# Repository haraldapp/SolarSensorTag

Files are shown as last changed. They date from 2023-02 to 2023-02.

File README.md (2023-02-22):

# SolarSensorTag
Smarthome Sensor mit Akku und Solarzelle  
Status: erste Prototypen als Temperatur+Luftfeuchte Sensor laufen seit 08/2022

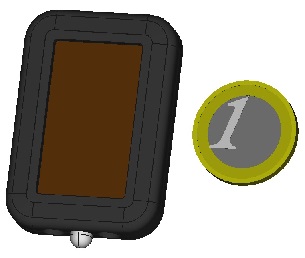
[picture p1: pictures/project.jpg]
> 

##  Features
- kleine Abmessungen
- Akku Ladungserhaltung bei etwas Tageslicht ohne direkte Sonne
- vielfache Bestückungsmöglichkeiten mit unterschiedlichen Sensoren
- Solarzelle und Gehäuse können von einer sehr preiswerten Mini-Taschenlampe verwendet werden (auch China Clones) - *"Solar Power Flash Light"* googeln

## Hardware
- Prozessor der SiLabs EFM32 Serie
- CC1101 Modul
- opt. EEPROM
- Solarzelle 4V
- Akku Kopfzelle, z.B. VL2020
- Dual-Color LED
- zum Gehäuse passende Leiterplatte
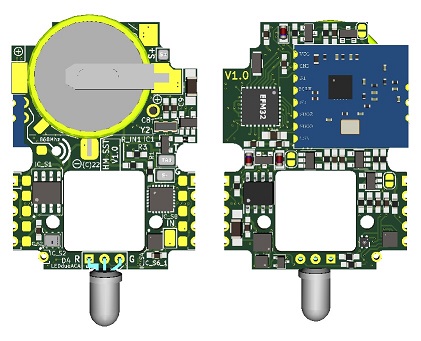
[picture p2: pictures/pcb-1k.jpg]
  
- Aufbau
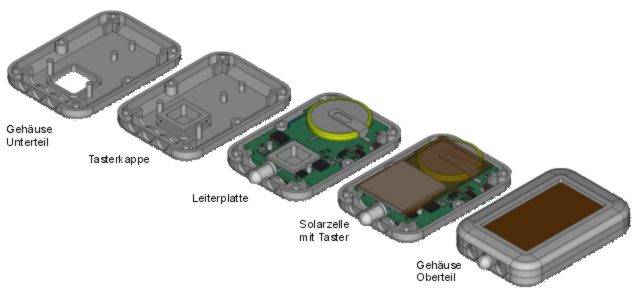
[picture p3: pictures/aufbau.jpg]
   
 
## Software
- Entwicklungsumgebung Silicon Labs Simplicity Studio mit GeckoSDK
- Unfangreiches eigenes API mit Arduino ähnlichen Funktionen, das auf dem SiLabs GeckoSDK aufsetzt  
  (damit sind Sourcecode Teile aus Arduino Sketches einsetzbar)
- Watchdog
- Schutz des Akkus vor Überladung durch Software
- Menü zur Bedienung mit einem Button 
- Debug Ausgabe (emuliert)
- verschiedene RF Protokolle sind in der Entwicklung, u.a.  
  Homematic [ASKSINPP](https://github.com/pa-pa/AskSinPP)
- STM32 Version geplant, wenn MCU's verfügbar sind 
  
## Projekte
- [HM-WDS10-TH-I](projects/HM-WDS10-TH/README.md "")/HM-WDS10-TH-O Temperatur/Feutigkeitssensor

## Add on's
- Halter für Blumentöpfe [```JPG```](addon/plantsticker/plant-sticker.jpg) [```STL```](addon/plantsticker/plant-sticker.stl)
   
## Getting Started
- keine Zeit? dann direkt zu einer Projektseite wechseln
- Schaltplan mit allen Optionen [```PDF```](efm32/schematics/SolarSensorTagEFM32-schematics.pdf) [```JPG```](efm32/schematics/SolarSensorTagEFM32-schematics.jpg)
- Bauteileliste mit allen Optionen [```PDF```](efm32/partlist/SolarSensorTagEFM32-parts.pdf)
- PCB im Verzeichnis efm32/pcb/gerber
- Bestückungsplan [```PDF```](efm32/pcb/assembly/SolarSensorTagEFM32-assembly.pdf)

## Entwicklung
- Programmieradapter [```README```](develop/progadapt/README.md)

## Lizenz
- [Creative Commons 3.0](http://creativecommons.org/licenses/by-nc-sa/3.0/de/)  
  
<br><br>
   
**Thanks to**
+ [pa-pa](https://github.com/pa-pa) für seine Arbeit an ASKSINPP

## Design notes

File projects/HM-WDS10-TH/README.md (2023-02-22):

# HM-WDS-10
Temperatur+Luftfeuchte Sensor for Homematic

## Bauteile
- die STT Leiterplatte wird mit wenigen Bauteilen bestückt  
  Bestückungsliste [``PDF``](SolarSensorTag-THSensor-Parts.pdf)
- zum Einsatz kommt ein VL2020/HFN Akku mit Lötfahnen der direkt auf der Leiterplatte bestückt wird  

## Aufbau

Als Basis für Solarzelle und Gehäuse dient eine Mini-Taschenlampe (hier China Clone). 

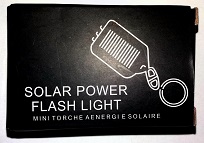
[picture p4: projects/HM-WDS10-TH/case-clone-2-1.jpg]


Bei manchen Geäusen muß man noch einen/zwei Abstandhalter oder Stifte (rot) entfernen damit die Leiterplatte rein passt. Einige Clones haben statt einem Akku nur eine CR2032 Batterie - aber bisher alle - eine funktionierende Solarzelle. Die Leiterplatte mit Taster ist dann manchmal so aufgeklebt, daß man die Anschlüsse der Solarzelle nicht sieht.

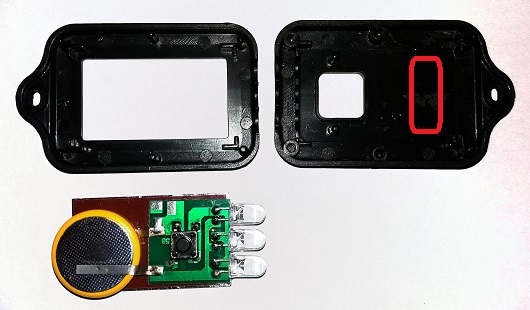
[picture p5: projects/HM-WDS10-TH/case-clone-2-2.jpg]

 
Ggf. Leiterplatte mit Taster ablösen und an der richtigen Stelle aufkleben. Batterie und LEDs entfernen und Anschlussdrähte anlöten.  
Achtung (!) sollte die Solarzelle bisher nicht angeschlossen sein:  
Die Kontakte der Solarzelle lassen sich meist nur mit Niedertemperatur Lötzinn verlöten, da diese sonst wegbrennen. Hier ist es besser das (+) Kabel mit einem Tropfen UV Kleber zu befestigen und die Verbindung mit Silberleitlack herzustellen.

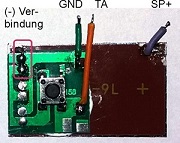
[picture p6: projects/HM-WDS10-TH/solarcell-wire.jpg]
 

Oberseite der VL2020 Batterie mit einem Stück Tesa isolieren. 
Verbindungen an die Leiterplatte anlöten und alles ins Gehäuse einpassen.

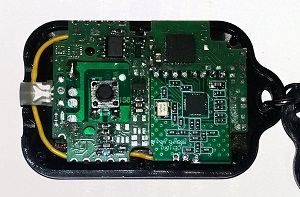
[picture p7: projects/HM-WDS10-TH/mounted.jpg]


## Bedienung
- Die Bedieung erfolt über den Taster. Anders als bei bei Standard Homematic Sensoren ist ein Menü implementiert über das mehrere Funktionen auswählbar sind.  
   [siehe doc](/source/doc/menu-states.jpg)

## Lizenz
- [Creative Commons 3.0](http://creativecommons.org/licenses/by-nc-sa/3.0/de/)  
  
<br><br>
**Thanks to**
+ [pa-pa](https://github.com/pa-pa) für seine Arbeit an ASKSINPP

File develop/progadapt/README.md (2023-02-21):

# SST Programming Adapter

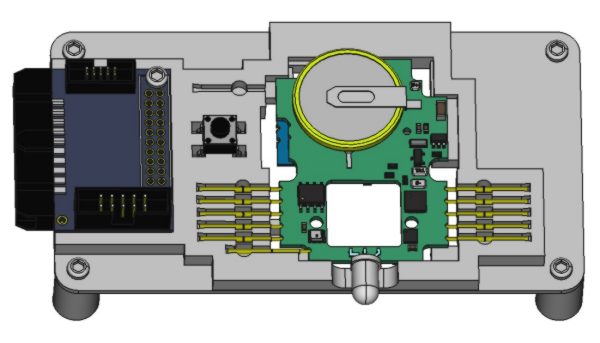
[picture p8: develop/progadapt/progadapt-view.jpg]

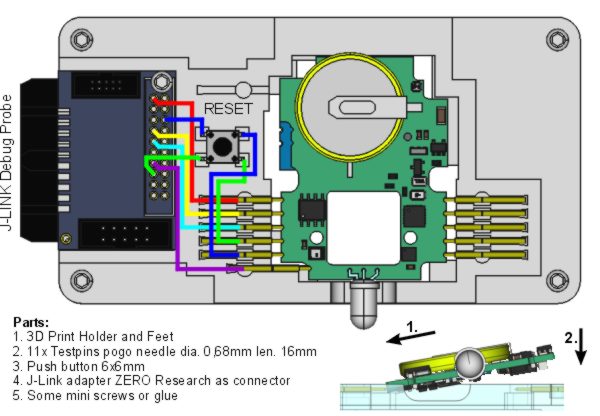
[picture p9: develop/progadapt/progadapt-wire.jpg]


#  3D Print
- 1x body [```STL```](progadap-body.stl)
- 4x feet [```STL```](progadap-body.stl)

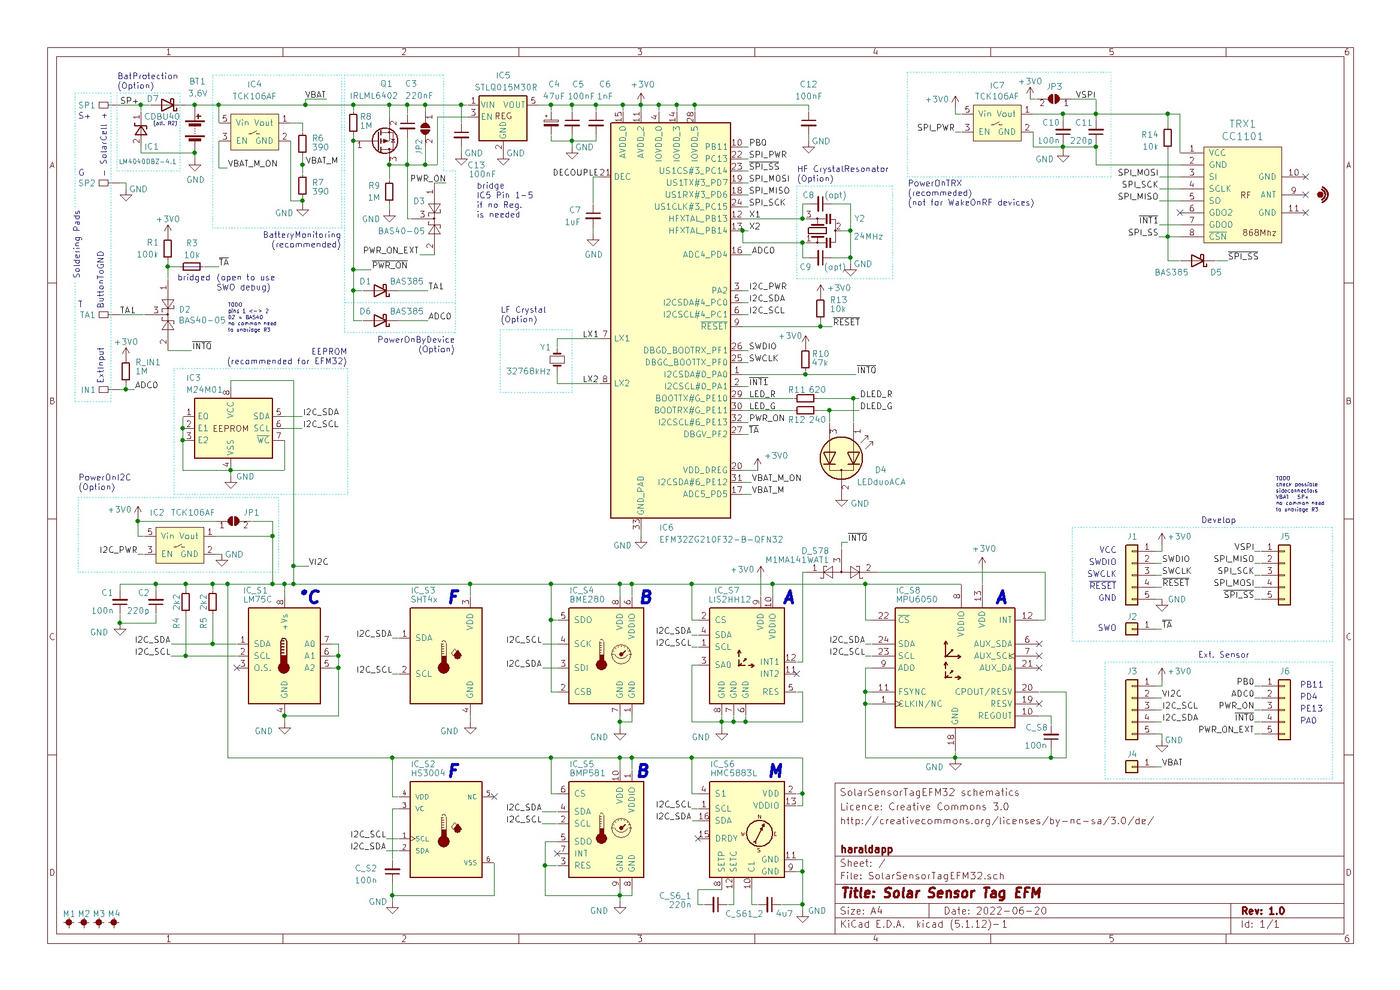
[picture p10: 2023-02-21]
efm32/schematics/SolarSensorTagEFM32-schematics.jpg

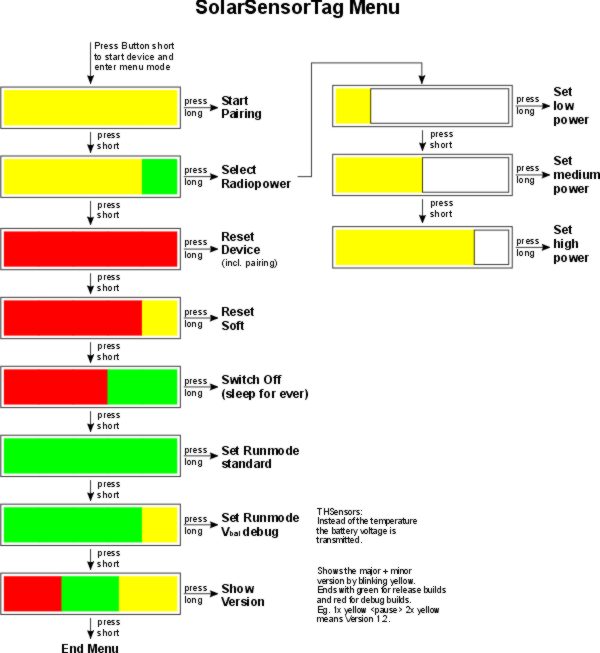
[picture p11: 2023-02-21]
source/doc/menu-states.jpg

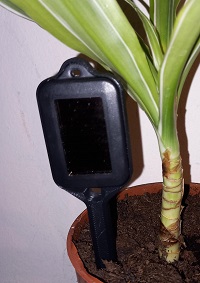
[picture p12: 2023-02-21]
addon/plantsticker/plant-sticker.jpg

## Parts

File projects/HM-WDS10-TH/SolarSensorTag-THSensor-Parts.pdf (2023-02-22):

## Solar Sensor Tag EFM THSensor parts

Reduced part list for TH sensors with VL2020 battery

Ref | Value | Size / Case / Spec | PartNo. / Alternatives
THSensor project
IC3 | M24256 | SOIC-8 3,9mm P1.27mm, EEPROM | M24256E-FMN6TP M24256-BRMN6TP M24M01-DFMN6TP
IC5 | Reg. 3,0V | bridge pin 1-5
IC6 | EFM32 | QFN-32, MCU AMTEL (EFM32HG210F32 for release not tested) | EFM32HG210F64-B-QFN32
IC7 | TCK106AF | SOT23-5 | TCK106AF,LF
IC_S3 | SHT4x | SHT4x 1.5x1.5mm P0.8mm | SHT40-AD1B-R2 SHT40A SHT41A
D2 | BAS40-05 | SOT-23, common cathode, low leakage or bridge pin 2-3 | BAS40-05 BAS70-05 BAT54C
D4 | LED RedGreen | 5mm/3mm, THT, 3Pin, common cathode | WP59SURKCGKW
D5 | BAS385 | MicroMELF, 0603, 0805, low leakage | CDBU40
D7 | 150 | 0603 (resistor instead of diode)
C1 | 100n | 0603 | CL10B104KA8NNWC
C4 | 47uF 6,3V | 1206, X5R, poss. Tantal 1210 low height | CL31A476MQHNNNE
C5 | 100nF | 0603
C6 | 1nF | 0603
C7 | 1uF | 0805 | CL21B105KAFNNNE
C10 | 100nF | 0603
C11 | 220pF | 0603
C12 | 100nF | 0603
R3 | 10k | unbridge for debug
R4 | 6k8 | 0603, I2C pullup
R5 | 6k8 | 0603, I2C pullup
R10 | 47k | 0603
R11 | 620 | 0603
R12 | 240 | 0603
R13 | 10k | 0603
R14 | 10k | 0603
JP1 | | bridge
TRX1 | CC1101 868MHz | 19x17mm module
ANT | 83mm 868MHz | isolated wire antenna
BT1 | VL2020 | Li.Va. battery cell with solder tabs Charge end 3.4V, Discharge end: 2,5V! max. short load current not spec.! | VL2020/1HF VL2020/HFN BL2020
TA1 | PushButton | 6x6mm … from CASE
SP1 | SC-3722-9 | SolarPanel 4V, 37x22mm … from CASE
LP | HM SST V1.0 | PCB, 31,2x41,2mm, 4-layer
CASE | | SolarPowerFlashLight

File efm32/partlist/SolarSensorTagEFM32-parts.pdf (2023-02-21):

## Solar Sensor Tag EFM parts

Ref | Value | Size / Case / Spec | PartNo. / Alternatives
Core
IC5 | Reg. 3,0V | SOT23-5, nano power LDO regulator | STLQ015M30R SPX3819M5-L-3-0/TR
IC6 | EFM32 | QFN-32, MCU AMTEL | EFM32HG210F64-B-QFN32
D2 | BAS40-05 | SOT-23, common cathode, low leakage | BAS40-05 BAS70-05 BAT54C
D4 | LED RedGreen | 5mm/3mm, THT, 3Pin, common cathode | WP59SURKCGKW
D5 | BAS385 | MicroMELF, 0603, 0805, low leakage | CDBU40
D7 | CDBU40 | 0603
C1 | 100n | 0603 | CL10B104KA8NNWC
C2 | 220p | 0603
C4 | 47uF 6,3V | 1206, X5R, poss. tantal 1210 low height | CL31A476MQHNNNE
C5 | 100nF | 0603
C6 | 1nF | 0603
C7 | 1uF | 0805 | CL21B105KAFNNNE
C12 | 100nF | 0603
R1 | 100k | 0603 | (optional)
R3 | 10k | 0603, bridged by default
R4 | 2k2 / 4k7 | 0603, I2C pullup
R5 | 2k2 / 4k7 | 0603, I2C pullup
R10 | 47k | 0603
R11 | 620 | 0603
R12 | 240 | 0603
R13 | 10k | 0603
R14 | 10k | 0603
TRX1 | CC1101 868MHz | 19x17mm module
ANT | 83mm 868MHz | isolated wire antenna
BT1 | LIR2025 | Li.Ion/Li.Po/Li.Va battery cell with solder tabs (2025 + 2032 only with high case 0) | LIR2025 BMW LIR2025-LBY2 (1,60 R) (VL2020 see options) (ML2020 see options)
TA1 | PushButton | 6x6mm … see CASE
SP1 | SC-3722-9 | SolarPanel 4V, 37x22mm … see CASE
LP | HM SST V.10 | PCB, 31,2x41,2mm, 4-layer
CASE | | 3D-Print or SolarPowerFlashLight
HF Crystal Resonator (option)
Y2 | 24MHz | SMD3215 Resonator 3pin 3.2x1.3mm | CSTNE24M0VH3C000R0 CSTNE24M0VH5T000R0
C8 | (opt) | 0603, optional
C9 | (opt) | 0603, optional
LF Crystal (option)
Y1 | 32768kHz | SMD3215 2pin 3.2x1.5mm | SC32S-7PF20PPM (0,43 D) (0,34 M)

EEPROM (option, recommended)
IC3 | M24256 | SOIC-8 3,9mm P1.27mm, EEPROM >=256kBit (32kB) | M24256E-FMN6TP M24256-BRMN6TP

M24M01-DFMN6TP
BatteryMonitoring (option, recommended for LiIo battery and 3V reg.)
IC4 | TCK106AF | SOT23-5
R6 | 390 / 100 | 0603
R7 | 390 / 220 | 0603
PowerOnTRX (option, recommended)
IC7 | TCK106AF | SOT23-5 | TCK106AF,LF
C10 | 100n | 0603
C11 | 220p | 0603
PowerOnI2C (option)
IC2 | TCK106AF | SOT23-5
PowerOnByDevice (option)
Q1 | IRLML6402 | SOT-23 | IRLML2244 IRLML9301
D1 | BAS385 | MicroMELF, 0603, 0805, low leakage
D3 | BAS40-05 | SOT-23, common cathode, low leakage | BAS70-05 BAT54C
C3 | 220nF | 0603
R8 | 1M | 0603
R9 | 1M | 0603
BatProtection (option, may only be needed for outdoor/direct sunlight)
IC1 | LM4040DBZ-4.1 | SOT-23 | LM4040DIM3-4.1 LM4040DYM3-4.1

BatteryVanadium (option) (3,0V vanadium rechargeable battery)
BT1 | VL2020 | Li.Va. battery cell with solder tabs Charge end 3.4V, Discharge end: 2,5V! max. short load current not spec.! | VL2020/1HF (2,70) VL2020/HFN BL2020
D7 | 150 | 0603, resistor
R4 | 6k8 | 0603, I2C pullup
R5 | 6k8 | 0603, I2C pullup
IC1 | LM4040DBZ-3.3 | SOT-23
IC5 | Reg. 3,0V | bridge pin 1-5
Q1 | IRLML6402
D1 | BAS385
D3 | BAS40-05
D6 | BAS385
C3 | 220nF
R8 | 1M
R9 | 1M
Sensor 0: (no sensor, e.g. 1 channel remote control) NanoPower see PowerOnByDevice
D6 | BAS385 | MicroMELF, 0603, 0805, low leakage
TA2 | PushButton | 6x6mm, ext. KonfigBtn IN1 GND
Sensor 1: Temperature
IC_S1 | LM75C | SOIC-8 P1.27mm
Sensor 2: Temperature + Humidity
IC_S2 | HS3004 | 6LGA P1.0mm | HS3004 (2,19 M) (2,14 D)
C_S2 | 100n | 0603
Sensor 3: Temperature + Humidity
IC_S3 | SHT4x | SHT4x 1.5x1.5mm P0.8mm | SHT40-AD1B-R2 SHT40A

SHT41A
Sensor 4: Temperatur + Barometer
IC_S4 | BME280 | Bosch_LGA | BMP280 (6,88 D)
Sensor 5: Temperatur + Barometer
IC_S5 | BMP581 | Bosch_HLGA | BMP581 (5,60 D)
Sensor 6: Compass (experimental, design rule „no copper under the case“ cannot be implemented)
IC_S6 | HMC5883L | LGA-16 P0.5mm
C_S61_1 | 220n | 0603
C_S61_2 | 4u7 | 1206
Sensor 7: Accelerometer (3-Axxis)
IC_S7 | LIS2HH12 | LGA-12 P0.5mm | LIS2HH12 (1,65 D)
D_S78 | M1MA141WAT 1 | SOT-323, SC-70, common anode, low leakage | M1MA141WAT1 DAP202U

Sensor 8: Accelerometer (6-Axxis)
IC_S8 | MPU6050 | QFN-24 P0.5mm | MPU-6050 (7,60 M) ICM-20689 TDK (6,66 D)
D_S78 | M1MA141WAT 1 | SOT-323, SC-70, common anode | M1MA141WAT1 DAP202U
C_S8 | 100n | 0603
Sensor 9: Ext. Input/PushButton/Switch/WindowContact
R_IN1 | 1M | 0603 | or as C 47nF
Sensor 10: 1/2-channel remote control
R_IN1 | 47k | 0603
SW_EXT | SW1 | 6x6mm external config. switch
Sensor EXT: staggered sensor PCB with solder connections J3 J4 J6
R1 | 100k | not mounted
R3 | 10k | not mounted
R_IN1 | 1M | not mounted
IC_S1 | LM75C | not mounted
IC_S2 | HS3004 | not mounted
C_S2 | 100n | not mounted
IC_S6 | HMC5883L | not mounted
C_S61_1 | 220n | not mounted
C_S61_2 | 4u7 | not mounted
IC_S4 | BME280 | not mounted
IC_S8 | MPU6050 | not mounted
D_S78 | BAS70-06 | not mounted
C_S8 | 100n | not mounted

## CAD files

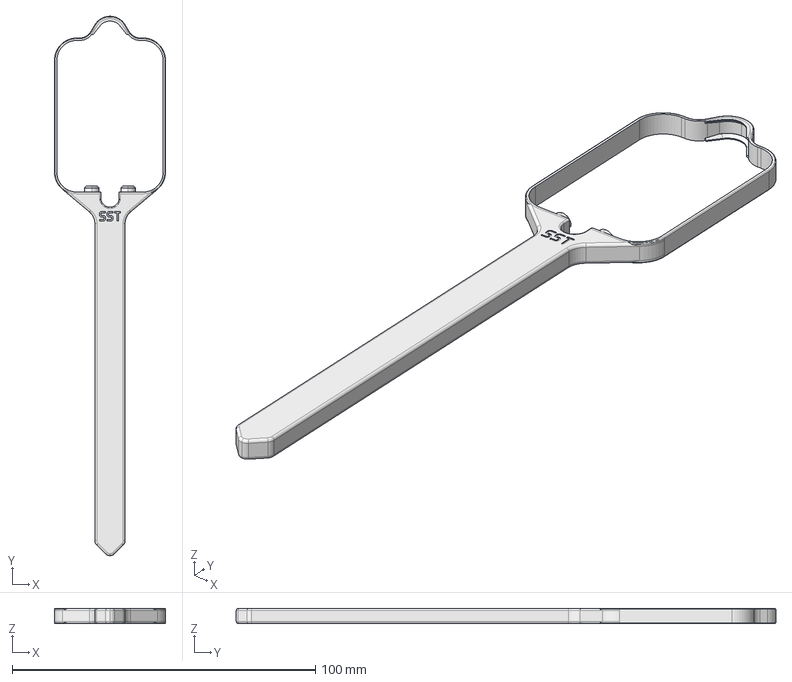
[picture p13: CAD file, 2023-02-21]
addon/plantsticker/PlantSticker.FCStd
36.6 x 178.0 x 5.00 mm

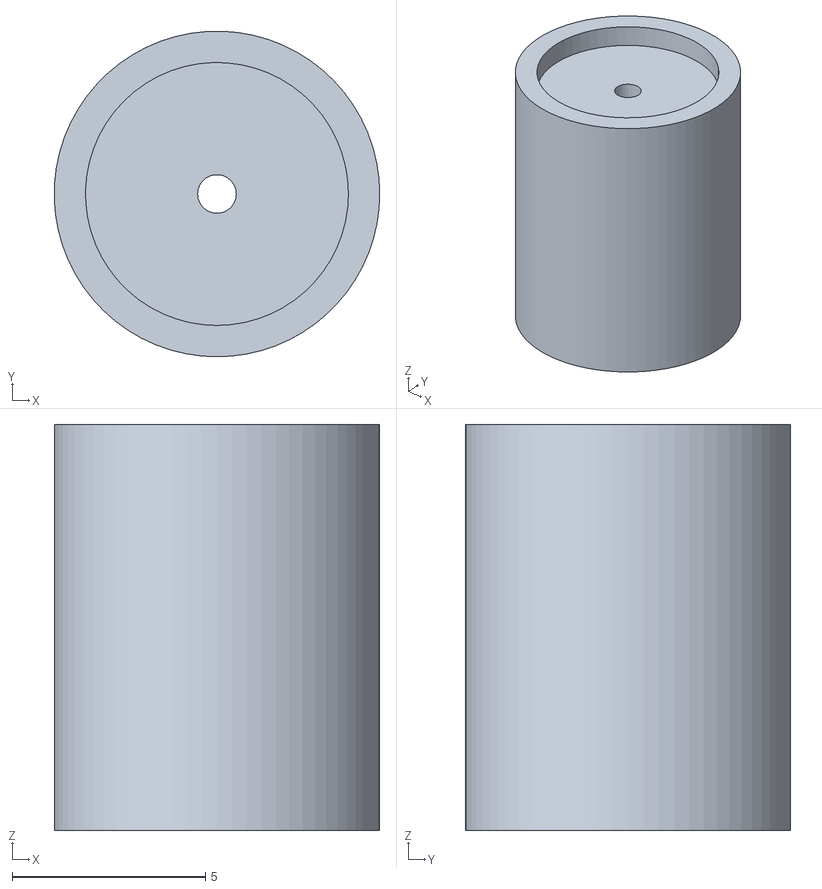
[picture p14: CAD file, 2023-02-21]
develop/progadapt/progadapt-feet.stl
8.42 x 8.42 x 10.5

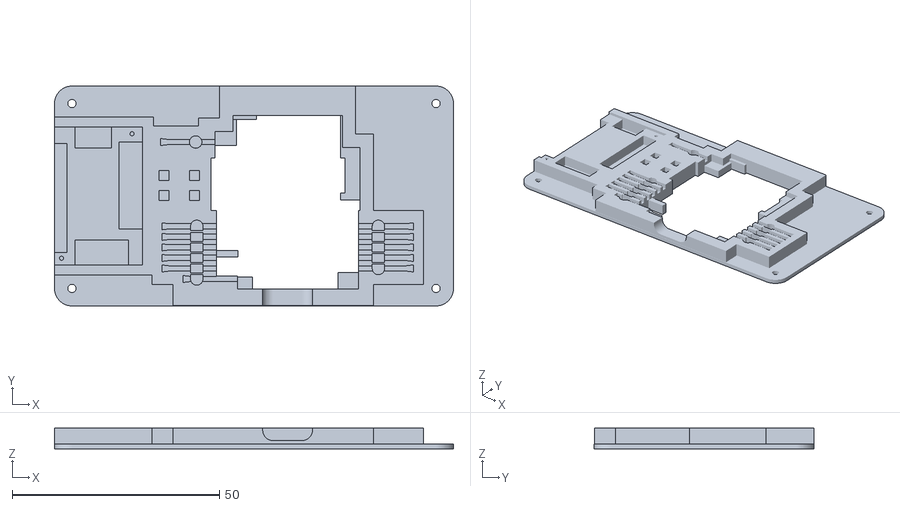
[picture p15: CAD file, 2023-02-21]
develop/progadapt/progadapt-body.stl
96.2 x 53.0 x 5.00

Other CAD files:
addon/plantsticker/plant-sticker.stl

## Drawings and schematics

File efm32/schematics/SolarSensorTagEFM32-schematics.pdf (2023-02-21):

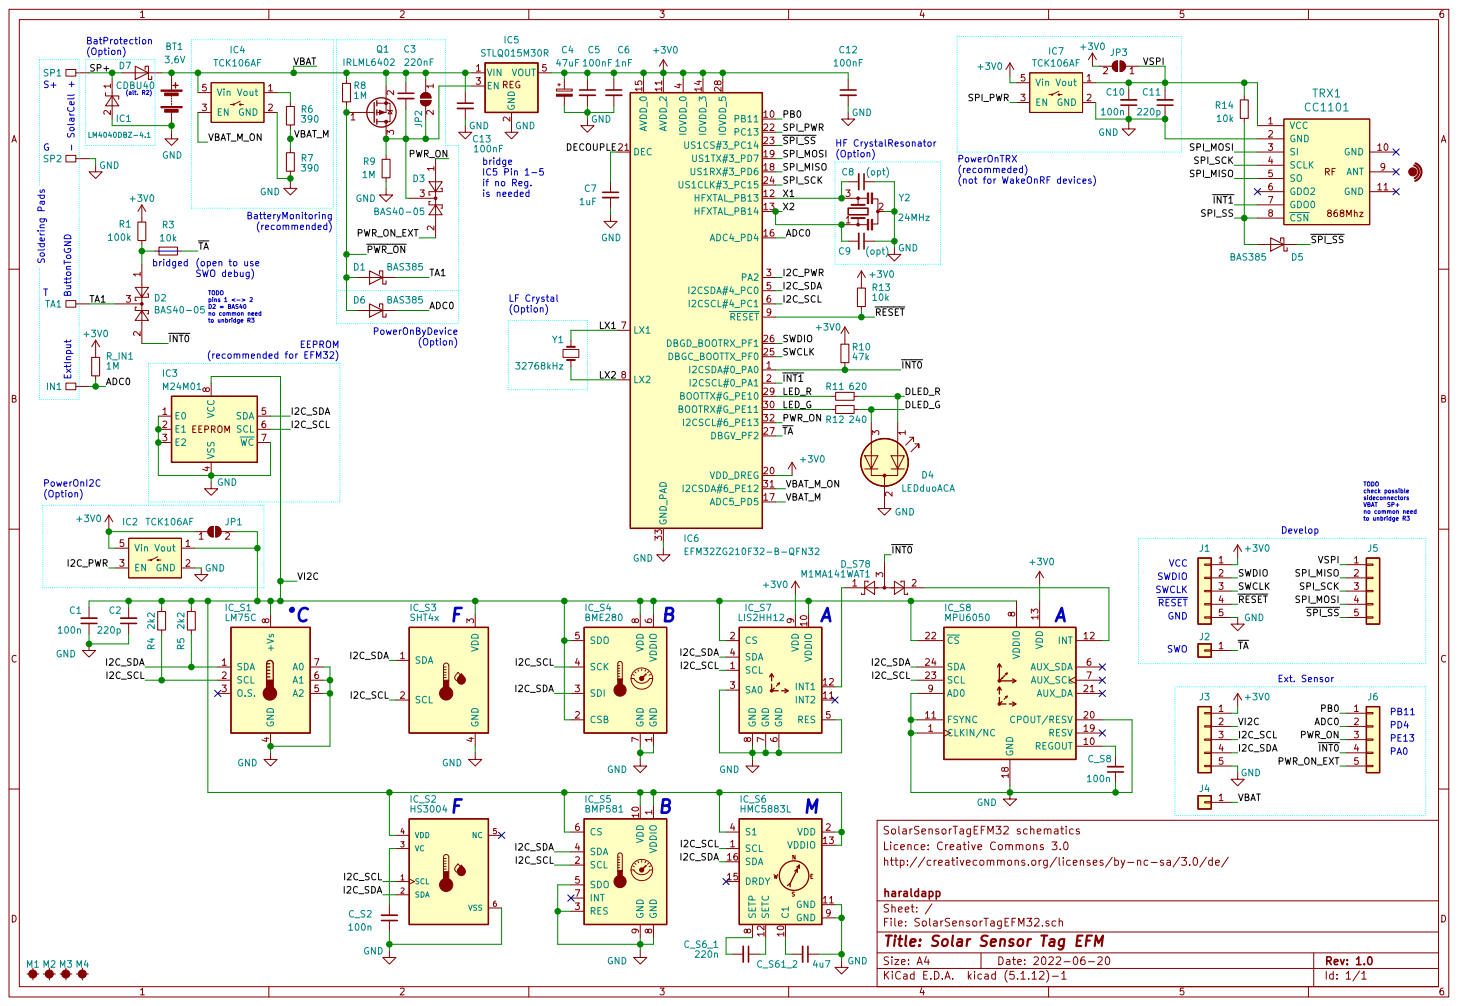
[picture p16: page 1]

to unbridge R3 TODO pins 1 <-> 2 D2 = BAS40

4 SDA 5 SCL 6 WC 7 VCC

http://creativecommons.org/licenses/by-nc-sa/3.0/de/ Licence: Creative Commons 3.0 SolarSensorTagEFM32 schematics C1

IC_S1 | IC_S4 BME280 | IC_S7 | IC_S8 MPU6050

1 CSB 2 SDI 3 SCK 4 SDO 5 VDDIO

1 VDD 10 SCL 2 RES 3 SDA 4 SDO 5 CS 6

File: SolarSensorTagEFM32.sch Sheet: / haraldapp

Id: 1/1 Title: Solar Sensor Tag EFM

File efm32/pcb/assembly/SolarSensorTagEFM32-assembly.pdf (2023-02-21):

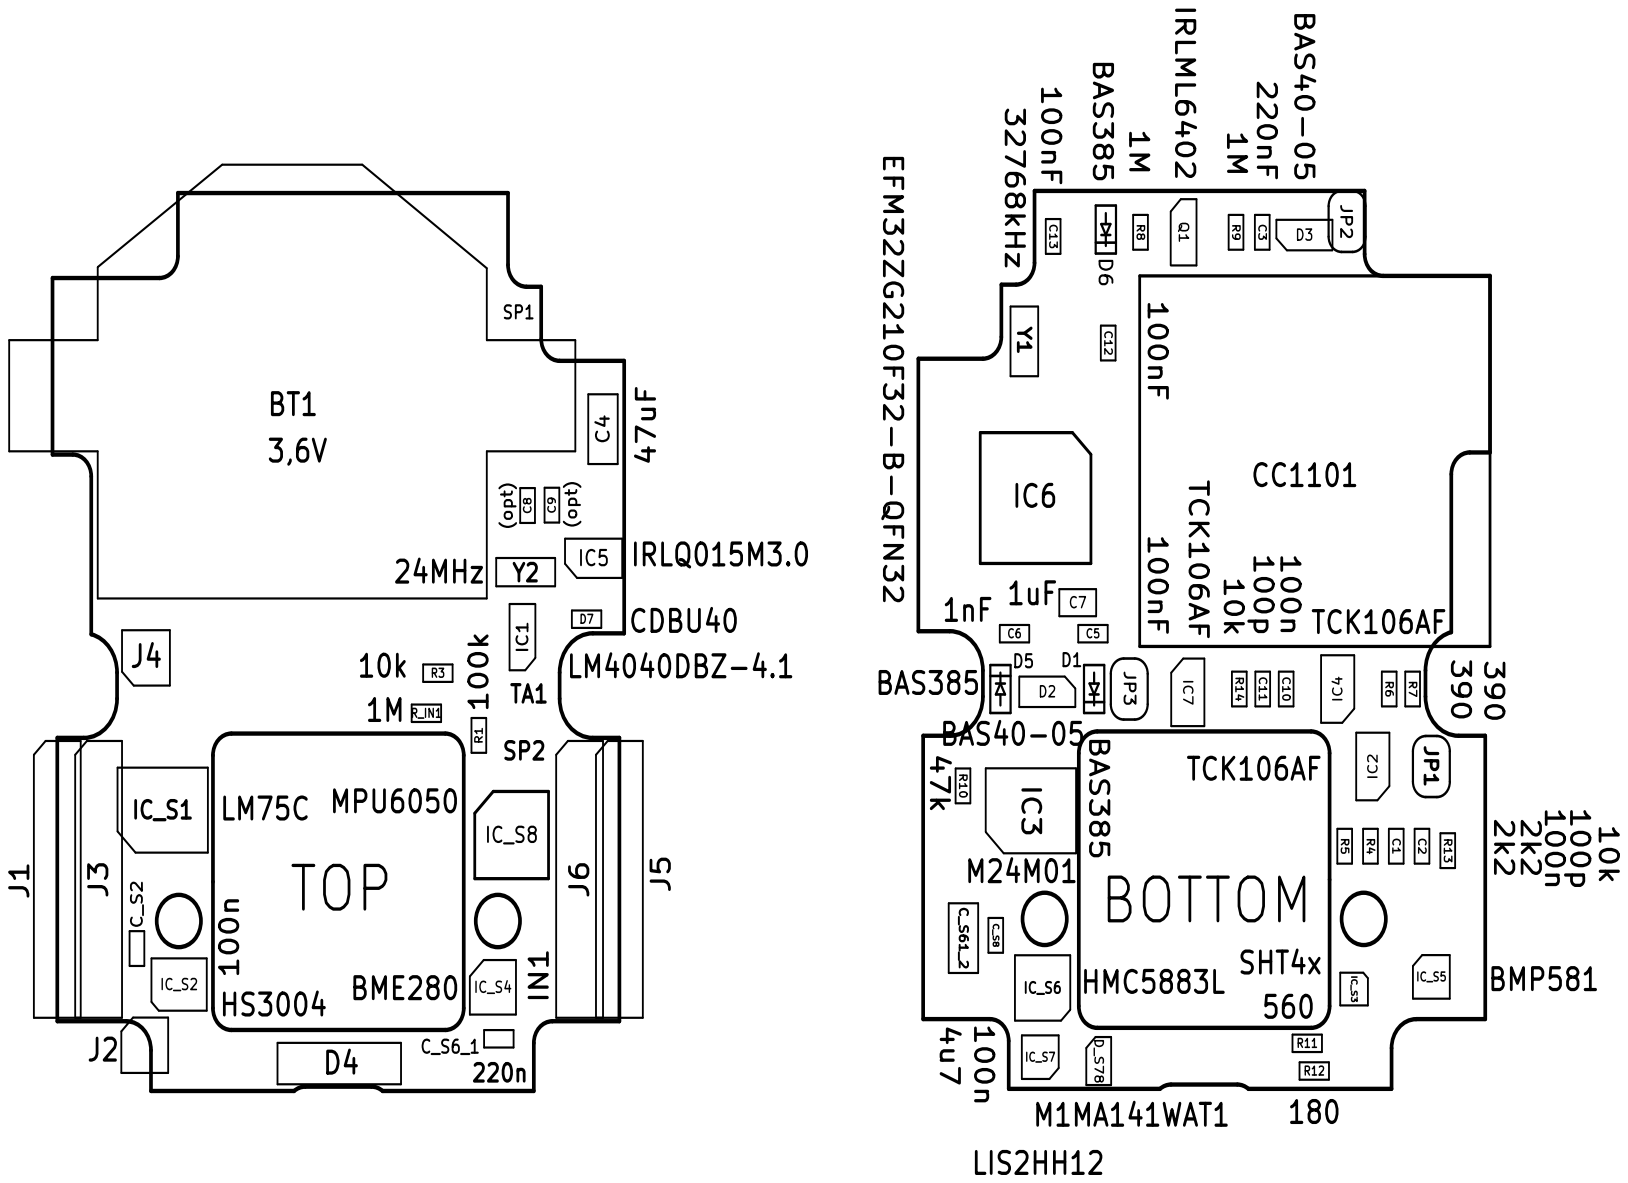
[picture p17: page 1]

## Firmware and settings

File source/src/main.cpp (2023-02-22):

//- -----------------------------------------------------------------------------------------------------------------------
// SolarSensorTag
// 2022-09-01 haraldapp Creative Commons - http://creativecommons.org/licenses/by-nc-sa/3.0/de/
//- -----------------------------------------------------------------------------------------------------------------------
// file: main.cpp
// Implements a ASKSINPP based code for some sensors on the SolarSensorTag hardware
//
// REFERENCES
// [1] AskSinPP https://github.com/pa-pa/AskSinPP and https://asksinpp.de/
//- -----------------------------------------------------------------------------------------------------------------------

// map aduino
#include "sst_arduino_geckosdk.h"

// to compile an individual SST sensor:
//  create a new configuration file, eg. sst_config_HM-WDS10-TH-O.h
//  set/add a build configuration with global define, eg. SST_CONFIG_FILE="sst_config_HM-WDS10-TH-O.h"
#ifdef SST_CONFIG_FILE
#include SST_CONFIG_FILE
#else
#error "no global define SST_CONFIG_FILE"
#endif

// Version
#define SST_VER_MAJOR 1
#define SST_VER_MINOR 2

// TODO implement asksin option wake up on radio
// TODO implement asksin AES using EFM32 hardware
// TODO implement SST option battery monitor
// TODO implement periodic polling for configuration changes (otherwise we have to push the button somewhere mounted devices)
// TODO optimize power consumption
// TODO    eg. asksin Radio-CC1101.h init() sets always MaxPower
// TODO    eg. asksin Radio-CC1101.h reduce EM0 runtime, check delays, current consumption is 47ms 5mA + 24ms 32mA
// TODO    eg. check if scaling down clocks has some effect on power consumption
// TODO optimize some code size

// asksin radio pins (radio.h)
#define MISO SPI_MISO_APIN
#define MOSI SPI_MOSI_APIN
#define SCK  SPI_SCK_APIN

// asksin storage (eeprom)
#ifndef SST_OPT_EEPROM_I2CADDR
#define SST_OPT_EEPROM_I2CADDR 0xA0
#endif
#if SST_OPT_EEPROM==0 // internal flash
 #error "eeprom internal flash not implemented"
#elif SST_OPT_EEPROM==1 // M24M01
 #define STORAGEDRIVER SST_EEPROM_M24MXX<SST_OPT_EEPROM_I2CADDR,128,256>
#elif  SST_OPT_EEPROM==2 // M24256
 #define STORAGEDRIVER SST_EEPROM_M24MXX<SST_OPT_EEPROM_I2CADDR,32,64>
#elif  SST_OPT_EEPROM==9 // M24xx compatible
 #ifndef SST_OPT_EEPROM_SIZE
 #error "SST_OPT_EEPROM_SIZE not defined"
 #endif
 #ifndef SST_OPT_EEPROM_PAGE
 #error "SST_OPT_EEPROM_PAGE not defined"
 #endif
 #define STORAGEDRIVER SST_EEPROM_M24MXX<SST_OPT_EEPROM_I2CADDR,SST_OPT_EEPROM_SIZE,64>
#endif

// asksin library
#define SPI_MODE0     0   // radio.h use template class LibSPI
#define EnableInterrupt_h   // asksinpp.h we have interrupts, do not use pin polling
#include "asksinpp.h"
#include "Register.h"
#include <MultiChannelDevice.h>
#include <Weather.h>
using namespace as;

// device info
static struct DeviceInfo devinfo = {
    {0x4e,0x52,0x12},            // Device ID
    "SST1234567",                // Device Serial
    {0x00,DEVICE_MODEL},         // Device Model
    0x10,                        // Firmware Version
    as::DeviceType::DEVICE_TYPE, // Device Type
    {0x01,0x00}                  // Info Bytes
};
// device ID and Serial from EFM32 chip ID (like USE_HW_SERIAL)
// remark:
//  to avoid modifying asksin code (see define USE_HW_SERIAL/Device.h)
//  we use a memory structure and initialize ID and Serial
//  early within a class constructor
SST_InitDeviceInfoFromHWSerial initDevInfo(devinfo.DeviceID,devinfo.Serial);

// radio
#ifndef RADIO_SENDDELAY
 #define RADIO_SENDDELAY 100
#endif
// custom config: reduce radio power
#define CONFIG_RADIOPOWER 3 // custom config offsets see asksinpp.h: CONFIG_FREQ1=0, CONFIG_FREQ2=1, CONFIG_BOOTSTATE=2
static uint8_t _sst_custom_radio_freq1=0;
static uint8_t _sst_custom_radio_freq2=0;
enum { sst_radiopower_notset=0, sst_radiopower_low=1, sst_radiopower_normal=2, sst_radiopower_max=3 };
static uint8_t _sst_custom_radio_power=sst_radiopower_normal;
typedef LibSPI<SPI_SS_APIN> SPIType;
#if !defined(SST_OPT_POWERON_TRX) || (SST_OPT_POWERON_TRX==0)
 typedef CC1101Radio<SPIType,INT1_APIN,NO_APIN,RADIO_SENDDELAY> RadioBaseType;
#else
 typedef CC1101Radio<SPIType,INT1_APIN,SPI_PWR_APIN,RADIO_SENDDELAY> RadioBaseType;
#endif
class RadioType : public RadioBaseType {
public:
  bool init () {
    // CC1101Radio:init() initializes
    //   CC1101_PATABLE=PA_MaxPower
    //   CC1101_FREQ2=0x21, CC1101_FREQ1=0x65, CC1101_FREQ0=0x6A (868.3 MHz)
    bool ret=RadioBaseType::init();
    if ( ret )  { // set custom config values on every radio init
      if( _sst_custom_radio_freq1>=0x60 && _sst_custom_radio_freq1<=0x6A )
        this->tuneFreq(0x21, _sst_custom_radio_freq1, _sst_custom_radio_freq2);
      if ( _sst_custom_radio_power==sst_radiopower_normal ) {
    	SSTPRINTS( _F("Set radio power normal\n") );
        initReg(CC1101_PATABLE, PA_Normal);
      }
      else if ( _sst_custom_radio_power==sst_radiopower_low ) {
      	SSTPRINTS( _F("Set radio power low\n") );
        initReg(CC1101_PATABLE, PA_LowPower);
      }
    }
    return ret;
  }
};

// led
static const LedStates::BlinkPattern _sst_led_blinkpattern_dual1_ex[] PROGMEM = SST_INIT_LED_BLINKPATTERN_DUAL1_EX;
static const LedStates::BlinkPattern _sst_led_blinkpattern_dual2_ex[] PROGMEM = SST_INIT_LED_BLINKPATTERN_DUAL2_EX;
class LedType : public SSTLedType<Led<ArduinoPins>,LedStates,LedStates::Mode,LedStates::BlinkPattern> {
public:
  LedType() : SSTLedType(_sst_led_blinkpattern_dual1_ex,_sst_led_blinkpattern_dual2_ex) {};
};

// battery
#if SST_OPT_BATTERY>0
//  defaults for battery measue interval
#if (DEVICE_TYPE==THSensor) && !defined(SST_OPT_BATTERY_INTERVAL)
#define SST_OPT_BATTERY_INTERVAL 0 // battery measured on every sensor measure
#endif
//  defaults for VL2020 (Vanadium-Lithium)
#if (SST_OPT_BATTERY==1) && !defined(SST_OPT_BATTERY_LOW)
#define SST_OPT_BATTERY_LOW 27
#endif
#if (SST_OPT_BATTERY==1) && !defined(SST_OPT_BATTERY_CRITICAL)
#define SST_OPT_BATTERY_CRITICAL 26
#endif
#if (SST_OPT_BATTERY==1) && !defined(SST_OPT_BATTERY_OVERCHARGE)
#define SST_OPT_BATTERY_OVERCHARGE 33
#endif
//  check battery paramters
#if !defined(SST_OPT_BATTERY_LOW) || !defined(SST_OPT_BATTERY_CRITICAL) || !defined(SST_OPT_BATTERY_INTERVAL) || !defined(SST_OPT_BATTERY_OVERCHARGE)
#error "missing battery parameters SST_OPT_BATTERY_xxx"
#endif

class BatterySensorType : public Alarm {
  uint32_t  m_Period;
  uint8_t   m_Low, m_Critical, m_Overcharge;
  uint16_t  m_Vcc;
  uint8_t   m_OverchargeProtect;
  uint8_t   m_OverchargeMeasure;
 public:
  BatterySensorType () : Alarm(0), m_Period(0), m_Low(0), m_Critical(0), m_Overcharge(0), m_Vcc(0),
                         m_OverchargeProtect(0), m_OverchargeMeasure(0) {
  }
  virtual ~BatterySensorType() {
  }
  // SST software overcharge protection
  #if SST_OPT_BATTERY_PROTECTION>0
  bool overchargeProtect( AlarmClock& clock, LedType& led ) {
    if ( m_OverchargeMeasure>0 ) {
      m_OverchargeMeasure=0;
      SSTLedOverChargeMode ledorg=led.overcharge();
      led.overcharge(sst_ledovercharge_off); // check
      Delay(10); measure();
      led.overcharge(ledorg);
    }
    if ( overcharge() ) {
      led.overcharge(sst_ledovercharge_on); // (re)initialize protection
      if ( m_OverchargeProtect==0 ) {
        SSTPRINTS( _F("Start battery overcharge protection\n") );
    	SST_SYSTICK_AddCallbackParam( overchargeProtectTickSecCB, 1000, this );
      }
      m_OverchargeProtect=1;
    }
    else if ( m_OverchargeProtect>0 && overchargedone() ) {
      led.overcharge(sst_ledovercharge_none);
      if ( m_OverchargeProtect>4*60 ) { // check at least for 4 minutes
        SST_SYSTICK_RemoveCallback( (void*)overchargeProtectTickSecCB );
        m_OverchargeProtect=0; m_OverchargeMeasure=0;
        SSTPRINTS( _F("End battery overcharge protection\n") );
      }
    }
    return (m_OverchargeProtect!=0);
  }
  static void overchargeProtectTickSecCB( void *param )  {
	  // SSTPRINTS( "o" );
      SST_Watchdog_Feed();
	  BatterySensorType *pThis=((BatterySensorType*)param);
      uint8_t& OverchargeProtect=pThis->m_OverchargeProtect;
      if ( OverchargeProtect>0 && OverchargeProtect<255 )   OverchargeProtect++; // next protection step
      uint8_t& OverchargeMeasure=pThis->m_OverchargeMeasure;
      if ( OverchargeMeasure<255 )  OverchargeMeasure++;
  }
  #else
  bool overchargeProtect( LedType& led ) { return false; }
  #endif
  virtual void trigger( AlarmClock& clock ) {
    measure();
    if ( m_Period>0 ) { set(m_Period); clock.add(*this); }
  }
  // BattSensor basics
  uint8_t current() const { return (m_Vcc+50)/100; }
  bool critical() const { return current()<m_Critical; }
  void critical(uint8_t value) { m_Critical=value; }
  bool low() const { return current()<m_Low; }
  void low (uint8_t value) { m_Low=value; }
  bool overcharge() const { return (m_Vcc+50)/100>m_Overcharge; }
  bool overchargecritical() const { return (m_Vcc+50)/100>m_Overcharge+1; }
  bool overchargedone() const { return (m_Vcc/100)<=m_Overcharge; }
  void overcharge(uint8_t value) { m_Overcharge=value; }
  void resetCurrent() { m_Vcc=0; }
  void init(uint32_t period,AlarmClock& clock) {
    SST_ADC_Init();
    measure();
    m_Period=period; set(m_Period);
    if ( period>0 )  clock.add(*this);
  }
  void measure() {
    #if SST_OPT_BATTERYMONITOR==1
    // TODO implement SST option battery monitor
    #error "not implemented: SST_OPT_BATTERYMONITOR"
    #else
    SST_ADC_MeasureInternalVCC( m_Vcc );
    SSTPRINTF( _F("iVcc: %u\n"), m_Vcc );
    #endif
  }
  void setIdle () {}
  void unsetIdle () {}
  // for backward compatibility
  uint16_t voltageHighRes() { return m_Vcc; }
  uint8_t voltage() { return current(); }
  // asksin METER for compatibility
  BatterySensorType& meter() { return *this; }
  BatterySensorType& sensor() { return *this; }
  void start () {}
  uint16_t value () const { return m_Vcc; }
  uint16_t finish () { measure(); return m_Vcc; }
};
#endif // #if SST_OPT_BATTERY>0


// asksin hal extended
//  battery overcharge
//  customized radio frequency and radio power
typedef AskSin<LedType,BatterySensorType,RadioType> HALBASETYPE;
class Hal : public HALBASETYPE {
public:
  void initBattery(uint16_t interval,uint8_t low,uint8_t critical,uint8_t overcharge) {
    battery.init(seconds2ticks(interval),sysclock);
    battery.low(low);
    battery.critical(critical);
    battery.overcharge(overcharge);
  }
  void config(const StorageConfig& sc) { // called by device::init
    if ( sc.valid()==true )  { // read custom radio setting - set by radio.init
      _sst_custom_radio_freq1=sc.getByte(CONFIG_FREQ1);
      _sst_custom_radio_freq2=sc.getByte(CONFIG_FREQ2);
      _sst_custom_radio_power=sc.getByte(CONFIG_RADIOPOWER);
      if ( _sst_custom_radio_power==sst_radiopower_notset )   _sst_custom_radio_power=sst_radiopower_normal;
    }
  }
  void config_setradiofreq(StorageConfig sc, uint8_t f1, uint8_t f2 ) {
    _sst_custom_radio_freq1=f1; sc.setByte(CONFIG_FREQ1,f1);
    _sst_custom_radio_freq2=f2; sc.setByte(CONFIG_FREQ2,f2);
    sc.validate();
  }
  void config_setradiopower(StorageConfig sc, uint8_t p ) {
    _sst_custom_radio_power=p; sc.setByte(CONFIG_RADIOPOWER,p);
    sc.validate();
  }
  uint8_t config_getradiopower() {
    return _sst_custom_radio_power;
  }
} hal;

// sensors

// temperature+humidity sensor
#if DEVICE_TYPE == THSensor
class WeatherSensor : public Alarm {
  // sensor	SHT4X is assembled
  #if SST_OPT_BATTERY_DEBUGTEST==1
   class SSTInternalVCCSensor m_sensor;
  #elif SST_OPT_SENSOR_SHT4X>0
   #if (SST_OPT_SENSOR_SHT4X==1) && !defined(SST_OPT_SENSOR_SHT4X_ADDR)
   #define SST_OPT_SENSOR_SHT4X_ADDR 0x44
   #endif
   #if (SST_OPT_SENSOR_SHT4X==2) && !defined(SST_OPT_SENSOR_SHT4X_ADDR)
   #define SST_OPT_SENSOR_SHT4X_ADDR 0x45
   #endif
   #if !defined(SST_OPT_SENSOR_SHT4X_ADDR)
   #error "SST_OPT_SENSOR_SHT4X_ADDR not defined"
   #endif
   class SensorSHT4x<SST_OPT_SENSOR_SHT4X_ADDR> m_sensor;
  #else
   #error "no weather sensor defined"
  #endif
public:
  WeatherSensor () { }
  virtual ~WeatherSensor () { }
  void init () {
    m_sensor.init(); // initialize the sensor
  }
  uint16_t before () const {
    return 3000; // return how many milliseconds the measure should start in front of sending the message
  }
  virtual void trigger (__attribute__ ((unused)) AlarmClock& clock) {
    DPRINT("Measure...  ");
    hal.battery.meter().resetCurrent();
    hal.battery.meter().measure();
    bool ok=m_sensor.measure();
    if ( ok )  { DPRINT("T: ");DDEC(m_sensor.temperature()/10);DPRINT(", H: ");DDECLN(m_sensor.humidity()); }
    else       { DPRINTLN(" error"); }
  }
  //  temperature+humidity (used by WeatherChannel)
  uint16_t temperature ()  {
    if ( SSTGetRunMode()==SST_RUNMODE_DEBUG_VBAT )  return hal.battery.meter().value()/10;
    return m_sensor.temperature();
  }
  uint8_t  humidity ()  {
    if ( SSTGetRunMode()==SST_RUNMODE_DEBUG_VBAT )  return 99;
    return m_sensor.humidity();
  }
};
// weather channel
// TODO implement periodic polling for configuration changes (otherwise we have to push the button somewhere mounted devices)
// asksin WeatherChannel measure rate is about 150 seconds +/- slot spread + EXTRAMILLIS, see AskSinBase::nextSendSlot
#ifndef PEERS_PER_CHANNEL
#define PEERS_PER_CHANNEL 6   // number of available peers per channel
#endif
#ifndef EXTRAMILLIS
#define EXTRAMILLIS       456 // millisecond extra time to better hit the slot
#endif
// WeatherSensor List0 registers
//  the one and only device parameter is "wake up on radio"
DEFREGISTER(WeatherRegsList0,MASTERID_REGS,DREG_BURSTRX)
typedef RegList0<WeatherRegsList0> WeatherList0;
typedef WeatherChannel<Hal,SysClock,WeatherSensor,PEERS_PER_CHANNEL,EXTRAMILLIS,WeatherList0> SSTWeatherChannelType;
class SSTWeatherChannel : public SSTWeatherChannelType {
public:
  SSTWeatherChannel() : SSTWeatherChannelType() {
  }
  virtual ~SSTWeatherChannel() {
  }
  RTCAlarm& alarm() {
    return *this; // RTCAlarm is a protected base class, make it public
  }
};
typedef MultiChannelDevice<Hal,SSTWeatherChannel,1,WeatherList0> SSTDeviceTypeBase;
#endif // #if DEVICE_TYPE == THSensor

// asksin device
#if SST_OPT_RADIO_FREQADJUST==1
typedef SSTRadioFreqAdjust<SSTDeviceTypeBase,DeviceInfo,Message,AlarmClock,Alarm> SSTDeviceType;
#else
typedef SSTDeviceTypeBase SSTDeviceType;
#endif

class SSTDevice : public SSTDeviceType {
public:
  SSTDevice(const DeviceInfo& i,uint16_t addr) : SSTDeviceType(i,addr) {
  }
  virtual ~SSTDevice() {
  }
  void reset () {
    SSTDeviceTypeBase::reset();
    Delay(200);
    SST_SystemReset();
    // CONFIG_FREQ1
  }
  void freqadjust( uint8_t set ) {
    #if SST_OPT_RADIO_FREQADJUST==1
    if ( set==0 )   stopRadioFreqAdjust();
    if ( set==1 )   startRadioFreqAdjust();
    if ( set==2 )   toogleRadioFreqAdjust();
    #endif
  }
  bool freqadjust() {
    #if SST_OPT_RADIO_FREQADJUST==1
    return radioFreqAdjust();
    #else
    return false;
    #endif
  }
};
SSTDevice sdev(devinfo,0x20);

// ConfigButton
#if SST_OPT_RADIO_FREQADJUST==1
const uint8_t cfgBtnMenu[]=SST_BUTTONMENU_THSENSOR_DEVELOP;
#else
const uint8_t cfgBtnMenu[]=SST_BUTTONMENU_THSENSOR;
#endif
#define CFGBTNMENUSZE (sizeof(cfgBtnMenu)/sizeof(uint8_t))
typedef SSTMenuButton<SSTDevice,StateButton<>,LedStates,SST_VER_MAJOR,SST_VER_MINOR> SSTButtonType;
class SSTButton : public SSTButtonType {
public:
  SSTButton() : SSTButtonType(sdev,cfgBtnMenu,CFGBTNMENUSZE,seconds2ticks(2)) {
  };
  virtual void measure() {
    #if DEVICE_TYPE == THSensor
    SSTWeatherChannel& channel=sdev.channel(1);
    WeatherSensor& sensor=channel.sensors();
    uint32_t delay=1000; uint32_t before=sensor.before();
    SSTPRINTS( "Menu measure\n" );
    sysclock.cancel(channel.alarm());
    sysclock.instance().cancel(sensor);
    sysclock.instance().add(channel.alarm(),delay+before);
    sysclock.instance().add(sensor,delay);
    #endif
  }
} cfgBtn;

void setup( void )
{
  // check battery voltage first to avoid getting in a brownout reset loop
  #if SST_OPT_BATTERY>0
  if ( SST_GetSytemResetCause()==SST_RESETCAUSE_BROWNOUT )
    SST_SleepForever();
  if ( !SST_ADC_CheckInternalVCC(SST_OPT_BATTERY_CRITICAL,LED_R_APIN) )
    SST_SleepForever();
  #endif
  // init debug
  #if (SST_OPT_SWO_DEBUG==1) && !defined(NDEBUG)
  // SSTTestSWODebugBitrate( SST_OPT_SWO_DEBUG_BITRATE );
  DINITSWO( SST_OPT_SWO_DEBUG_BITRATE, SST_SWODEBUG_MODE_TIMER ); // 30000
  DPRINTLN( _F("setup()") );
  #endif
  // init watchdog
  #if ( SST_OPT_DISABLE_WATCHDOG!=1 )
  SST_Watchdog_Init( 30 );
  #endif
  DHWINFO();
  DPRINTLN(SST_ARDUINO_GECKOSDK_IDENTIFIER);
  DPRINTLN(ASKSIN_PLUS_PLUS_IDENTIFIER);
  DDEVINFO(sdev);
  // init I2C
  SST_I2C_PowerUp( SST_OPT_POWERON_I2C );
  SST_I2C_Init(); // Delay(1);
  // init asksin device
  DPRINTLN( _F("sdev.init") );
  sdev.init(hal);
  DPRINTLN( _F("buttonISR") );
  buttonISR(cfgBtn,INT0_APIN);
  sdev.initDone();
  DPRINTLN( _F("sdev.initDone") );
  // init SysClock and RTC
  SST_SYSTICK_AddCallback( callback, 1000/TICKS_PER_SECOND ); // SysClock callback defined in AlarmClock
  SST_RTC_Init();
  // init battery
  DPRINTLN( _F(" hal.initBattery") );
  hal.initBattery(SST_OPT_BATTERY_INTERVAL,SST_OPT_BATTERY_LOW,SST_OPT_BATTERY_CRITICAL,SST_OPT_BATTERY_OVERCHARGE);
  hal.activity.stayAwake(seconds2ticks(5));
  DPRINTLN( _F("setup() Done") );
}

void loop( void )
{
  bool worked = hal.runready();
  bool poll = sdev.pollRadio();
  bool freqadjust = sdev.freqadjust();
  bool btnmenu= cfgBtn.isActive();
  if ( worked==false && poll==false && freqadjust==false && btnmenu==false ) {
    if ( hal.battery.critical() || cfgBtn.switchOff() ) {
      // sleep in EM4 until button pressed
      SSTSleep<Hal,SysClock>::SleepForever(hal);
    }
    #if SST_OPT_BATTERY_PROTECTION==1
    else if ( hal.battery.overchargeProtect(sysclock,hal.led) ) {
      // keep on running consuming power with leds on
      // switch on radio to consume power, if overcharge gets critical
      bool critical=hal.battery.overchargecritical();
      bool stayawake=hal.activity.stayAwake();
      if ( critical && !stayawake )  { stayawake=true; hal.activity.stayAwake(seconds2ticks(10)); hal.wakeup(); }
      if ( !critical && !stayawake ) hal.setIdle();
    }
    #endif
    else  {
      // sleep in EM2 with low power RTC wakeup
      typedef SSTSleep<Hal,SysClock,TICKS_PER_SECOND> Sleep;
      hal.activity.savePower<Sleep,Hal>(hal); // note: asksin savePower: sleeps only when ready to sleep, otherwise returns to continue loop
    }
  }
}

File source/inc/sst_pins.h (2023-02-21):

// SST pin names
// xxx_PIN    pin number for gecko sdk gpio functions
// xxx_PORT   port number for gecko sdk gpio functions
// xxx_APIN   pin for arduino like api functions (see sst_arduino_gecksdk.h)

#ifndef _SST_PINS_H_
#define _SST_PINS_H_

#define GPIOPORTA 0
#define GPIOPORTB 1
#define GPIOPORTC 2
#define GPIOPORTD 3
#define GPIOPORTE 4
#define GPIOPORTF 5

#define INT0_PIN                       (0U)
#define INT0_PORT                      (gpioPortA)
#define INT0_APIN                      MAKE_APIN(GPIOPORTA,INT0_PIN)

#define INT1_PIN                       (1U)
#define INT1_PORT                      (gpioPortA)
#define INT1_APIN                      MAKE_APIN(GPIOPORTA,INT1_PIN)

#define I2C_PWR_PIN                    (2U)
#define I2C_PWR_PORT                   (gpioPortA)
#define I2C_PWR_APIN                   MAKE_APIN(GPIOPORTA,I2C_PWR_PIN)

#define LX1_PIN                        (7U)
#define LX1_PORT                       (gpioPortB)

#define LX2_PIN                        (8U)
#define LX2_PORT                       (gpioPortB)

#define PB0_PIN                        (11U)
#define PB0_PORT                       (gpioPortB)
#define PB0_APIN                       MAKE_APIN(GPIOPORTB,PB0_PIN)

#define X1_PIN                         (13U)
#define X1_PORT                        (gpioPortB)

#define X2_PIN                         (14U)
#define X2_PORT                        (gpioPortB)

#define I2C_SDA_PIN                    (0U)
#define I2C_SDA_PORT                   (gpioPortC)
#define I2C_SDA_APIN                   MAKE_APIN(GPIOPORTC,I2C_SDA_PIN)

#define I2C_SCL_PIN                    (1U)
#define I2C_SCL_PORT                   (gpioPortC)
#define I2C_SCL_APIN                   MAKE_APIN(GPIOPORTC,I2C_SCL_PIN)

#define SPI_PWR_PIN                    (13U)
#define SPI_PWR_PORT                   (gpioPortC)
#define SPI_PWR_APIN                   MAKE_APIN(GPIOPORTC,SPI_PWR_PIN)

#define SPI_SS_PIN                     (14U)
#define SPI_SS_PORT                    (gpioPortC)
#define SPI_SS_APIN                    MAKE_APIN(GPIOPORTC,SPI_SS_PIN)

#define SPI_SCK_PIN                    (15U)
#define SPI_SCK_PORT                   (gpioPortC)
#define SPI_SCK_APIN                   MAKE_APIN(GPIOPORTC,SPI_SCK_PIN)

#define ADC0_PIN                       (4U)
#define ADC0_PORT                      (gpioPortD)
#define ADC0_APIN                      MAKE_APIN(GPIOPORTD,ADC0_PIN)

#define VBAT_M_PIN                     (5U)
#define VBAT_M_PORT                    (gpioPortD)
#define VBAT_M_APIN                    MAKE_APIN(GPIOPORTD,VBAT_M_PIN)

#define SPI_MISO_PIN                   (6U)
#define SPI_MISO_PORT                  (gpioPortD)
#define SPI_MISO_APIN                  MAKE_APIN(GPIOPORTD,SPI_MISO_PIN)

#define SPI_MOSI_PIN                   (7U)
#define SPI_MOSI_PORT                  (gpioPortD)
#define SPI_MOSI_APIN                  MAKE_APIN(GPIOPORTD,SPI_MOSI_PIN)

#define LED_R_PIN                      (10U)
#define LED_R_PORT                     (gpioPortE)
#define LED_R_APORT                    4
#define LED_R_APIN                     MAKE_APIN(GPIOPORTE,LED_R_PIN)

#define LED_G_PIN                      (11U)
#define LED_G_PORT                     (gpioPortE)
#define LED_G_APORT                    4
#define LED_G_APIN                     MAKE_APIN(GPIOPORTE,LED_G_PIN)

#define VBAT_M_ON_PIN                  (12U)
#define VBAT_M_ON_PORT                 (gpioPortE)
#define VBAT_M_ON_APIN                 MAKE_APIN(GPIOPORTE,VBAT_M_ON_PIN)

#define PWR_ON_PIN                     (13U)
#define PWR_ON_PORT                    (gpioPortE)
#define PWR_ON_APIN                    MAKE_APIN(GPIOPORTE,PWR_ON_PIN)

#define SWO_PIN                        (2U)
#define SWO_PORT                       (gpioPortF)
#define SWO_APIN                       MAKE_APIN(GPIOPORTF,SWO_PIN)

#endif // #ifndef _SST_PINS_H_

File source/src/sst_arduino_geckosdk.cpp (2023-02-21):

//- -----------------------------------------------------------------------------------------------------------------------
// SST Solar Sensor Tag
// 2022-09-01 haraldapp Creative Commons - http://creativecommons.org/licenses/by-nc-sa/3.0/de/
//- -----------------------------------------------------------------------------------------------------------------------
// file: sst_arduino_geckosdk.cpp
// API with ARDUINO like functions used by ASKSINPP based EFM32 GeckoSDK functions

#include <stdarg.h>
#include "sst_arduino_geckosdk.h"

#include <sst_em_device.h> // em_device like includes for SST supported mcu chips
// Gecko SDK platform/emlib/inc
#include "em_chip.h"
#include "em_core.h"
#include "em_cmu.h"
#include "em_emu.h"
#include "em_system.h"
#include "em_gpio.h"
#include "em_usart.h"
#include "em_timer.h"
#include "em_rtc.h"
#include "em_adc.h"
#include "em_i2c.h"
#include "em_rmu.h"
#include "em_wdog.h"
#include "em_dbg.h"
// #include "em_int.h"
// Gecko SDK platform/emdrv
//    common/inc
//    spidrv/inc
//    dmadrv/inc
#include "spidrv.h"
// Gecko SDK hardware/kit/common/drivers
#include "i2cspm.h" // i2c simply polled master
#include "udelay.h"

volatile uint8_t _sst_savepower_mode=0; // current em sleep mode
volatile uint16_t _sst_savepower_wakeupevent=0;

// GPIO
void pinMode(uint8_t apin, uint8_t amode)
{
	// SSTPRINTS( "pinMode(" ); SSTPRINTPIN(apin); SSTPRINTS( "," ); SSTPRINTI(amode); SSTPRINTS( ")\n" );
	CMU_ClockEnable(cmuClock_GPIO,true);
	if ( amode==INPUT )
	   GPIO_PinModeSet( PORT_APIN(apin), PIN_APIN(apin), gpioModeInput, 0 );
	else if ( amode==INPUT_PULLUP )
       GPIO_PinModeSet( PORT_APIN(apin), PIN_APIN(apin), gpioModeInputPull, 1 );
	else if ( amode==INPUT_PULLDOWN )
       GPIO_PinModeSet( PORT_APIN(apin), PIN_APIN(apin), gpioModeInputPull, 0 );
	else if ( amode==OUTPUT && GPIO_PinModeGet(PORT_APIN(apin), PIN_APIN(apin))!=gpioModePushPull )
       GPIO_PinModeSet( PORT_APIN(apin), PIN_APIN(apin), gpioModePushPull, 0 );
}

int digitalRead(uint8_t apin)
{
    return GPIO_PinInGet( PORT_APIN(apin), PIN_APIN(apin) );
}

void digitalWrite(uint8_t apin, uint8_t val)
{
  if ( apin!=SPI_SS_APIN )  {
  // SSTPRINTS( "digitalWrite(" ); SSTPRINTPIN(apin); SSTPRINTS( "," ); SSTPRINTU(val); SSTPRINTS( ")\n" );
  }
  if ( apin==SPI_PWR_APIN )  { val=(!val); }
  if (val)   GPIO_PinOutSet( PORT_APIN(apin), PIN_APIN(apin) );
  else       GPIO_PinOutClear( PORT_APIN(apin), PIN_APIN(apin) );
}

static uint8_t _sst_adc_reference=0;

void analogReference(uint8_t mode)
{
  _sst_adc_reference=(uint8_t)mode;
}

int analogGetReference(void)
{
  return _sst_adc_reference;
}

int analogRead(uint8_t apin)
{
	uint8_t adcinput=SST_ADC_APinToInput( apin );
	if ( adcinput==SST_ADC_INPUTSEL_NONE )  return 0;
	uint8_t adcres=SST_ADC_RES_OVS;
	uint16_t val=0; SST_ADC_Measure( val, adcinput, _sst_adc_reference, adcres );
	return val;
}

void analogWrite(uint8_t apin, int val)
{
	// TODO implement by PWM or IDAC
}

void SST_GPIO_PinModeSet( uint8_t port, uint8_t pin, uint8_t mode, uint8_t out )
{
  // SSTPRINTS( "GPIO_PinModeSet(" ); SSTPRINTPIN(MAKE_APIN(port,pin)); SSTPRINTS( "," ); SSTPRINTI(mode); SSTPRINTS( "," ); SSTPRINTI(out); SSTPRINTS( ")\n" );
  GPIO_PinModeSet( (GPIO_Port_TypeDef)port, pin, (GPIO_Mode_TypeDef)mode, out );
}


// Interrupts
//   at the moment only supporting intterrupts on INT0 = PA0 and INT1 = PA1
typedef struct { uint8_t apin; uint32_t mask; voidFuncPtr cb; } SST_INT_STATUS;
SST_INT_STATUS _sst_int_status[2]={{0},{0}};
enum { SST_INT_EVEN=0, SST_INT_ODD=1 };
inline SST_INT_STATUS& sst_int_status_from_apin( uint8_t apin )  { return ((apin&1) ? _sst_int_status[SST_INT_ODD] : _sst_int_status[SST_INT_EVEN]); }
inline uint8_t sst_int_status_index_from_apin( uint8_t apin )  { return (apin&1) ? SST_INT_ODD : SST_INT_EVEN; }

void sst_gpio_irqhandler( uint8_t int_type ) {
  SST_INT_STATUS& intstatus=_sst_int_status[int_type];
  SSTPRINTF( _F(" Int GPIO %a\n"), intstatus.apin );
  if ( _sst_savepower_mode )   _sst_savepower_wakeupevent|=(int_type==SST_INT_EVEN?SST_SAVEPOWER_WAKEUP_GPIO_EVEN:SST_SAVEPOWER_WAKEUP_GPIO_ODD);
  uint32_t flags = GPIO_IntGet();
  if ( (intstatus.mask&flags) && (intstatus.cb) )  (*(intstatus.cb))();
  GPIO_IntClear( flags );
}

extern "C" void GPIO_EVEN_IRQHandler( void )  { sst_gpio_irqhandler(SST_INT_EVEN); }
extern "C" void GPIO_ODD_IRQHandler( void )    { sst_gpio_irqhandler(SST_INT_ODD); }

bool SST_GPIO_WakeUpFromPin( uint8_t apin )
{
  if ( (apin&1) && (_sst_savepower_wakeupevent&SST_SAVEPOWER_WAKEUP_GPIO_ODD) && _sst_int_status[SST_INT_ODD].apin==apin )
    return true;
  if ( !(apin&1) && (_sst_savepower_wakeupevent&SST_SAVEPOWER_WAKEUP_GPIO_EVEN) && _sst_int_status[SST_INT_EVEN].apin==apin )
    return true;
  return false;
}

void enableInterrupt( uint8_t apin, voidFuncPtr callback, PinStatus mode )
{
	SSTPRINTF( "enableInterrupt(%a,%p,%u)\n", apin, callback, mode );
	NVIC_EnableIRQ(GPIO_ODD_IRQn); NVIC_EnableIRQ(GPIO_EVEN_IRQn);
	SST_INT_STATUS& int_status=sst_int_status_from_apin( apin );
	if ( int_status.mask )   GPIO_ExtIntConfig( PORT_APIN(int_status.apin), PIN_APIN(int_status.apin), PIN_APIN(int_status.apin), false, false, false );
	int_status.apin=apin; int_status.mask=(1 << PIN_APIN(apin)); int_status.cb=callback;
	GPIO_ExtIntConfig( PORT_APIN(apin), PIN_APIN(apin), PIN_APIN(apin), (mode==CHANGE || mode==RISING), (mode==CHANGE || mode==FALLING), true );
}

void disableInterrupt( uint8_t apin )
{
	SSTPRINTF( "disableInterrupt(%a)\n", apin );
	SST_INT_STATUS& int_status=sst_int_status_from_apin( apin );
	if ( int_status.mask )   GPIO_ExtIntConfig( PORT_APIN(int_status.apin), PIN_APIN(int_status.apin), PIN_APIN(int_status.apin), false, false, false );
	int_status.apin=0; int_status.mask=0; int_status.cb=(voidFuncPtr)0;
}

void attachInterrupt(pin_size_t interruptNumber, voidFuncPtr callback, PinStatus mode)
{
	SSTPRINTF( "attachInterrupt(%u,%x,%u) - not supported\n", interruptNumber, (uint32_t)callback, mode );
}

void detachInterrupt(pin_size_t interruptNumber)
{
	SSTPRINTF( "disableInterrupt(%u) - not supported\n", interruptNumber );
}

int8_t digitalPinToInterrupt(uint8_t apin)
{
  return NOT_AN_INTERRUPT; // -> use enableInterrupt
}

// Delay, ticks in milliseconds (trough SysTick_Handler)
volatile uint32_t g_msTicks=0;
#ifndef NDEBUG
volatile uint32_t g_msTicksNDebug=0;
volatile uint8_t g_msTicksDebugStop=0;
#else
#define g_msTicksNDebug g_msTicks
#endif
#ifndef SST_SYSTICK_CB_CNT
#define SST_SYSTICK_CB_CNT 3 // default used by asksin sysclock, SSTRadioFreqAdjust, BatteryOverchargeProtect
#endif
typedef struct { void *callback; uint32_t tickcb; uint32_t tickcur; void *param; } SSTSYSTICKCALLBACKENTRY;
volatile SSTSYSTICKCALLBACKENTRY g_msSysTickCallbacks[SST_SYSTICK_CB_CNT]={0};

static volatile uint32_t AddTickCount( uint32_t add )
{
  volatile uint32_t ret;
  CORE_ATOMIC_SECTION( g_msTicks+=add; ret=g_msTicks; )
  return ret;
}
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

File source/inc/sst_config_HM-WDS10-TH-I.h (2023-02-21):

// SST configuration file

// SST options
#define SST_OPT_BATTERYMONITOR       0           // 0=no external battery monitor, use internal vcc adc
                                                 // 1=ext. battery monitor assembled (IC4, R6, R7)
// define SST_OPT_BATTERYMONITOR_DIV 50          // voltage divider factor in 1/100
#define SST_OPT_POWERON_I2C          0           // 0=I2C power is always on (JP1 bridged)
                                                 // 1=I2C power switched (IC2 assembled)
                                                 // 2=auto detect (may not work in all assemblies)
#define SST_OPT_POWERON_TRX          1           // 0=SPI power is always on (JP3 bridged)
                                                 // 1=SPI power switched (IC7 assembled)
// #define SST_OPT_BITRATE_TRX          1000000   // SPI bitrate (default 1000000)
#define SST_OPT_EEPROM               2           // 0=no eeprom/use internal flash
                                                 // 1=M24M01
                                                 // 2=M24256
                                                 // 9=M24xxx compatible, define size and pagesize
// #define SST_OPT_EEPROM_I2CADDR    0xA0        // M24xxx compatible: i2c address
// #define SST_OPT_EEPROM_SIZE       32          // M24xxx compatible: eeprom size in kbytes                    (eg. M24M01: 128, M24256: 32)
// #define SST_OPT_EEPROM_PAGE       64          // M24xxx compatible: eeprom page size in bytes (default=256)  (eg. M24M01: 256, M24256: 64)
#define SST_OPT_SENSOR_SHT4X         1           // 0=not is assembled
                                                 // 1=IC53 SSHT4x (A-Type) sensor is assembled, i2c address 0x44
                                                 // 2=IC53 SSHT4x (B-Type) sensor is assembled, i2c address 0x45
// #define SST_OPT_SENSOR_SHT4X_ADDR 0x44        // define SSHT4x compatible device other I2C address
#define SST_OPT_DISABLE_WATCHDOG     0           // 1=Watchdog is disabled (eg. for debugging)
#define SST_OPT_SWO_DEBUG            1           // 1=SWO used for debug output (PF2 pin)
#define SST_OPT_SWO_DEBUG_BITRATE    30500       // SWO output bitrate see sst_arduino_geckosdk.cpp section "SWO debug"
#define SST_OPT_BATTERY              1           // 0=none
                                                 // 1=battery VL2020 is installed (Vanadium-Lithium full=3,3V, end of discharge 2,5V)
                                                 // 99=other (define your own battery parameters SST_OPT_BATTERY_xxx)
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
